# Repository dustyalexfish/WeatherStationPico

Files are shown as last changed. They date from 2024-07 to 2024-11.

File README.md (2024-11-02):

# WeatherStationPico
A data-logging weather station that uses a LCD display for user output, a potentiometer for user input, a DS3231 real time clock module and the DFRobot Weather Station v3.

The weather station is currently very buggy, and do not expect top-quality code, as I have not had years of experience with writing code for the Raspberry Pi Pico.

# Modifying the Code

In order to use the code, you will need to create a Pico Project, named WeatherStationPico. I recommend using a tool like the Raspberry Pi Pico Project Generator:  https://github.com/raspberrypi/pico-project-generator. You will need to download the Pico SDK and Pico Extras as well.

Compile the project for the first time, without the code, and then add in all of the code, and replace your CMakeLists.txt with the one specified in the project, replacing /path/to with your path to your Pico SDK and Pico Extras path.

# Required Parts

A Computer to Program the RPI Pico 

A 3D Printer (or an order from a 3D Printing company)

A roll of Filament (For your 3D printer)

**1** Raspberry Pi Pico               https://thepihut.com/products/raspberry-pi-pico?variant=41925332566211

**1** Half size Breadboard            https://thepihut.com/products/raspberry-pi-breadboard-half-size

**1** DFRobot Weather Station         https://thepihut.com/products/weather-station-kit-with-anemometer-wind-vane-rain-bucket

**1** Rotary Encoder                  (link needed)

**1** I2C LCD 16x2                    https://thepihut.com/products/i2c-16x2-arduino-lcd-display-module

**1** DS3231 RTC Module               https://tinyurl.com/ds3231-amazon

**~20** Male-to-Male Jumper Wires     https://thepihut.com/products/premium-male-male-jumper-wires-20-x-6-150mm
**~20** Male-to-Female Jumper Wires   https://thepihut.com/products/premium-female-male-extension-jumper-wires-20-x-12

**~20** M2.5 Screws and Nuts          https://thepihut.com/products/adafruit-black-nylon-screw-and-stand-off-set-m2-5-thread

A way to power the Raspberry Pi Pico (5V power required). I am using a Solar Panel to power my Weather Station.

# 3D Printing

In order to use this project, you will have to print the project box. The STL files and FreeCAD files are provided in the 3dmodels file for you to 3D print. I recommend printing out of ABS or PETG as PLA may warp in sunlight, unless you plan to keep the project box in the shade (which is possible, as the cables are quite long).

# Wiring

**LCD** Wire the LCD VCC-5V pin to your Raspberry Pi Pico 5V VBUS pin. Wire the GND pin to one of your Raspberry Pi Pico GND pins. Wire the SDA pin of your I2C lcd to GPIO6 on the Raspberry Pi Pico. Wire SCL on your LCD to GPIO7 on your Raspberry Pi Pico. 

**Rotary Encoder** Wire the CLK pin of your Rotary Encoder to GPIO pin two. Wire the DT pin to GPIO3. Wire the SW pin to GPIO4. Attach the + to your VBUS pin and the GND pin to one of the Raspberry Pi Pico's Ground pins.

**Weather Station** Wire the Weather Station Board TX pin to the Raspberry Pi Pico GPIO1. Wire the Weather Station Board RX pin to Raspberry Pi Pico GPIO0. Attach the 5V pin to VBUS, and the GND pin to one of the Raspberry Pi Pico's GND pins.

**DS3231 Module** Wire the I2C SDA pn to GPIO6 and the SCL pin to GPIO7. Attach the + pin to 5V and the GND pin to one of the Raspberry Pi Pico GND pins.

# Assembly

Once you have 3D printed the top lid of the case, you can screw in the LCD display with M2.5 screws to fix it in place. You will have to superglue the Rotary Encoder in place to the model. 

Wire all of the wires that exit the Weather Station board to exit through the holes in the top half of the project box. 

Once you have done this, plug in the Raspberry Pi Pico in to your PC, and upload the UF2 file provided (builds/WeatherStation-1.1) to your Raspberry Pi Pico. Screw in the lid, and you are now recording your own weather!

# Operation

In order to erase all data stored on Flash, hold down the potentiometer until the text 'Erase' appears on the display. Leave it to erase, and then reapply power to the device. In order to view previous logs, hold the potentiometer until two dots appear on the screen, and then scroll through logs that are stored on the system using the rotary encoder. For debug, hold down the rotary encoder until about 6 dots appear, and let go. You must be using a serial monitor to access the contents via USB, like Minicom. The system will dump data in flash in blocks of 256 to serial to access.

You now have a working Weather Station!

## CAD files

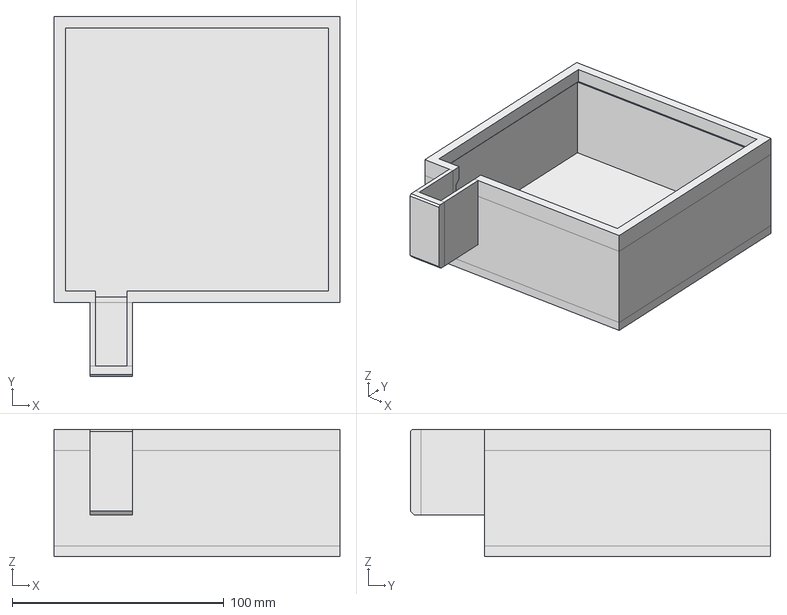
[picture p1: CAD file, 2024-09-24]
models/WeatherStationCap.FCStd
135.0 x 170.0 x 60.0 mm

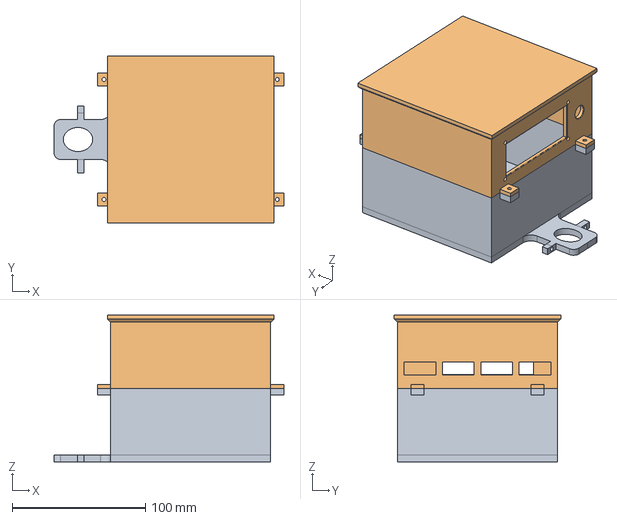
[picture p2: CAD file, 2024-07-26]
models/Project Box.FCStd
172.5 x 125.0 x 110.0 mm

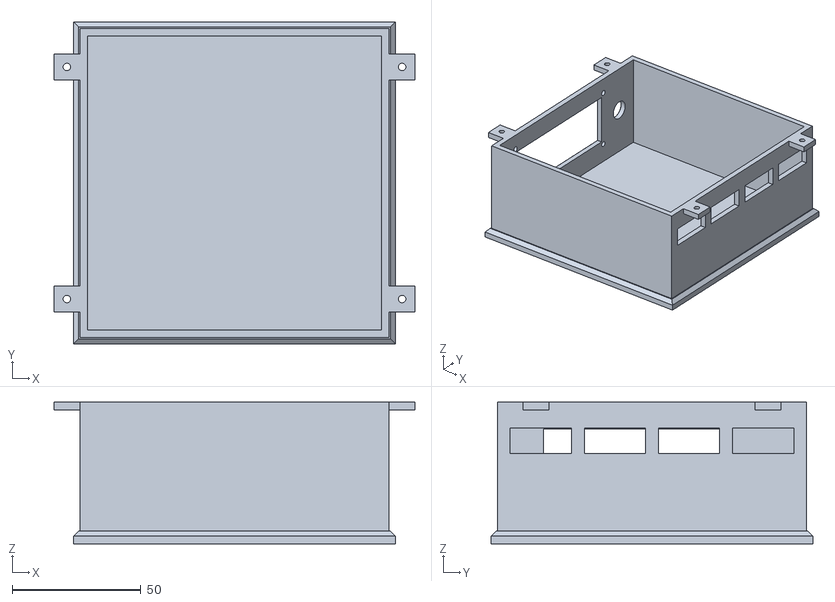
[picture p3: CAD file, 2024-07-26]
models/ProjectCase_top.stl
140.0 x 125.0 x 55.0

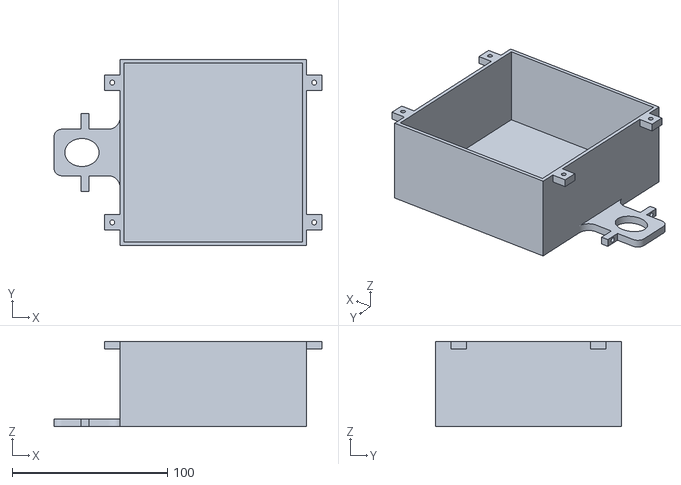
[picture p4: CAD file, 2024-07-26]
models/ProjectCase_bottom.stl
172.5 x 120.0 x 55.0

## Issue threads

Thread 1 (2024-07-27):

Pressure is flicking between being either too high or too low, only sometimes showing the correct air pressure

dustyalexfish, 2024-07-27:
The pressure reading on the Weather Station is sometimes wildly off the real pressure, either being around 3000 or 300hPa, only sometimes showing the actual air pressure

Closed 2024-07-27.

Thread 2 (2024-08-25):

The DS3231 is not reporting the year correctly

dustyalexfish, 2024-08-25:
When accessing the YEAR register on the DS3231, it reports 0b11111111, not the correct year. For a temporary fix, it currently just reports 2024

Closed 2024-09-22.

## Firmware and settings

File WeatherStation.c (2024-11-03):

#include "pico/sleep.h"
#include <math.h>

#include "hardware/rtc.h"
#include "pico/multicore.h"

#include "hardware/uart.h"
#include "hardware/i2c.h"
#include "hardware/irq.h"
#include "Recorder.h"
#include "lcd.h"
#include "RotaryEncoder.h"
#include "hardware/rtc.h"
#include "hardware/clocks.h"
#include "hardware/rosc.h"
#include "hardware/structs/scb.h"

#define LED_PIN 25
#define UART_ID uart0
#define BAUD_RATE 9600
#define DATA_BITS 8
#define PARITY UART_PARITY_NONE

#define STOP_BITS 1
#define UART_TX_PIN 0
#define UART_RX_PIN 1
#define I2C_SDA 6
#define I2C_SDL 7
#define SQW_PIN 16
#define I2C_PORT i2c1

#define MENUS 9

#define ENABLE_DORMANT true                  // Turn this ON if you are battery or solar powering your WeatherStation. However, Dormant mode is untested and is part of Pico Extras, so is unstable.
#define ENABLE_PROTOTYPE_LED false           // The onboard LED draws around 2 mA, and this is off to save that power
#define TURN_LCD_OFF_AFTER_TIME_EXPIRE true // I am not sure if turning this on reduces power, so it is by default off

int timeUntilLcdOffStart = 0;

const char* DIRECTIONS[8] = {"N ","NE", "E ", "SE", "S ", "SW", "W ", "NW"};
int time_since_interrupt();

const int ADDR = 0x27;

const int NUMBER_POT_STATES = 9;

volatile uint scb_orig;
volatile uint clock0_orig;
volatile uint clock1_orig;

static const char default_format[] = "%a %b %d %Y";

int intLen(int val)
{
  if (val <= 0)
  {
    return 1;
  }
  if (val <= 10)
  {
    return 1;
  }
  return (int)((ceil(log10(val))) * sizeof(char));
}

int shortLen(short val)
{
  if (val <= 0)
  {
    return 0;
  }
  return (int)((ceil(log10(val))) * sizeof(char));
}
bool display_flash_storage()
{
  lcd_home();
  char str[intLen(posInFlash / 20971)];
  sprintf(str, "%d", posInFlash / 20971);
  lcd_write_chars("Flash %: ", 9);
  lcd_write_chars(str, intLen(posInFlash / 16875));
  lcd_write_chars("%", 1);
  return true;
}

bool display_temp()
{
  lcd_home();
  int temperature = (((int)getTemperatureFromCompression()) - 32) * 5 / 9;
  char str[intLen(temperature)];
  sprintf(str, "%d", temperature);
  lcd_write_chars("Temperature: ", 13);
  lcd_write_chars(str, intLen(temperature));
  lcd_write_char('C');
  return true;
}
bool display_humid()
{
  lcd_home();
  int humidity = getHumidityFromCompression();
  char str[intLen(humidity) * sizeof(char)];
  sprintf(str, "%d", humidity);
  lcd_write_chars("Humidity: ", 10);
  lcd_write_chars(str, intLen(humidity) * sizeof(char));
  lcd_write_char('%');
  return true;
}

bool display_windSpeedAvg()
{
  lcd_home();
  int avgSpeed = getAvgSpeedFromCompression();
  char str[intLen(avgSpeed)];
  sprintf(str, "%d", avgSpeed);
  lcd_write_chars("Avg Spd: ", 9);
  lcd_write_chars(str, intLen(avgSpeed));
  lcd_write_chars("mph", 3);
  return true;
}
bool display_windSpeedFastest()
{
  lcd_home();
  int windSpeed = getFastestSpeedFromCompression();
  char str[intLen(windSpeed)];
  sprintf(str, "%d", windSpeed);
  lcd_write_chars("Fastest Speed: ", 15);
  lcd_home();
  shiftCursor(40);
  lcd_write_chars(str, intLen(windSpeed) * sizeof(char));
  lcd_write_chars("mph", 3);
  return false;
}
bool display_windRotation()
{
  lcd_home();
  int windRotation = getRotationFromCompression();
  lcd_write_chars("Wind Rot: ", 10);
  lcd_write_char(DIRECTIONS[windRotation][0]);
  lcd_write_char(DIRECTIONS[windRotation][1]);

  return true;
}
bool display_airPressure()
{
  lcd_home();
  int airPressure = getAirPressureFromCompression() / 10;
  char str[intLen(airPressure) * sizeof(char)];
  sprintf(str, "%d", airPressure);
  lcd_write_chars("Pressure: ", 10);
  lcd_write_chars(str, intLen(airPressure) * sizeof(char));

  return true;
}
bool display_rainfall_hour()
{
  lcd_home();
  int rainfall = (getRainfallOneHourFromCompression() * 25)/100;
  char str[intLen(rainfall)];
  sprintf(str, "%d", rainfall);
  lcd_write_chars("1h Rain: ", 9);
  lcd_write_chars(str, intLen(rainfall));
  lcd_write_chars("mm", 2);
  return true;
}
bool display_rainfall_day()
{
  lcd_home();
  int rainfall = (getRainfallOneDayFromCompression() * 25)/100;
  char str[intLen(rainfall)];
  sprintf(str, "%d", rainfall);
  lcd_write_chars("24h Rain: ", 10);
  lcd_write_chars(str, intLen(rainfall));
  lcd_write_chars("mm", 2);
  return true;
}

int pot_state = 0;
int tick_counter = 0;
int lastPotState = 0;

void initPins()
{
  stdio_uart_init();
  // stdio_usb_init();

  i2c_init(I2C_PORT, 50 * 1000);
  uart_init(UART_ID, BAUD_RATE);

  // LED

  uart_set_hw_flow(UART_ID, false, false);
  uart_set_format(UART_ID, DATA_BITS, STOP_BITS, PARITY);
  uart_set_fifo_enabled(UART_ID, false);
}

void updateLCD(int pot_state)
{
  if (lastPotState != pot_state)
  {
    lastPotState = pot_state;
    lcd_clear_screen();
  }
  lcd_home();
  // lcd_write_chars("Yay! ", 5);
  // busy_wait_ms(2);
  bool displayTime = true;

  switch (pot_state)
  {
  case 0:
    displayTime = display_flash_storage();
    break;
  case 2:
    displayTime = display_humid();
    break;
  case 3:
    displayTime = display_windSpeedAvg();
    break;
  case 4:
    displayTime = display_windSpeedFastest();
    break;
  case 5:
    displayTime = display_windRotation();
    break;
  case 6:
    displayTime = display_airPressure();
    break;
  case 7:
    displayTime = display_rainfall_hour();
    break;
  case 8:
    displayTime = display_rainfall_day();
    break;
  default:
    displayTime = display_temp();
    break;
  }

  if (displayTime)
  {
    lcd_home();
    char timeChars[intLen(wstime)];
    shiftCursor(40);
    sprintf(timeChars, "%d", wstime);
    lcd_write_chars("Time: ", 6);
    lcd_write_chars(timeChars, intLen(wstime));
  }
  // restore_interrupts(ints);
}

const int TIME_TURN_OFF = 10; // Turn off at 8:00 PM
const int TIME_TURN_ON = 7;   // turn back on at 7:00 AM

int scroll(int rotPos, int scrollBy, int numberOfFlashLogs)
{
  int rotPosition = rotPos;
  while (getRotaryEncoderSWPushState())
  {
    tight_loop_contents();
  }
  while (!getRotaryEncoderSWPushState())
  {
    getFlashLogContents(rotPosition);
    time_t rawtime = getTimeFromCompresion();
    struct tm ts;
    char buf[16];
    char buf2[16];
    for (int i = 0; i < 16; ++i)
    {
      buf[i] = ' ';
      buf2[i] = ' ';
    }
    // Format time, "ddd yyyy-mm-dd hh:mm:ss zzz"
    ts = *localtime(&rawtime);
    strftime(buf, sizeof(buf), "%a %d/%m/%Y", &ts);
    strftime(buf2, sizeof(buf2), "%H:%M:%S %Z", &ts);
    lcd_clear_screen();
    lcd_home();
    lcd_write_chars(buf, 16);
    shiftCursor(24);
    lcd_write_chars(buf2, 16);

    while (true)
    {
      int update = update_rotaryEncoder();
      if (update == ENCODER_CW)
      {
        rotPosition += scrollBy;
        rotPosition = rotPosition % numberOfFlashLogs;
        break;
      }
      if (update == ENCODER_CCW)
      {
        rotPosition -= scrollBy;
        if (rotPosition <= -1)
        {
          rotPosition = numberOfFlashLogs - 1;
        }
        rotPosition = rotPosition % numberOfFlashLogs;
        break;
      }
      if (getRotaryEncoderSWPushState())
      {
        break;
      }
    }
  }
  return rotPosition;
}
int numberRange(int max,char* question, int len, int start) {
  lcd_clear_screen();
  lcd_home();
  lcd_write_chars(question, len);

  while (getRotaryEncoderSWPushState())
  {
    tight_loop_contents();
  };
  int num = start;

  char str2[intLen(num)];
  sprintf(str2, "%d", num);
  shiftCursor(40-len);
  lcd_write_chars(str2, intLen(num));
  while(!getRotaryEncoderSWPushState()) {
    int update = update_rotaryEncoder();

    num = num % max;
    if (update == ENCODER_CW) {
      num++;
    } else if (update == ENCODER_CCW) {
      num--;
    }
    if(update != ENCODER_NO_ACTIVITY) {
      char str[intLen(num)];
      sprintf(str, "%d", num);
      lcd_home();
      shiftCursor(40);
      lcd_write_chars(str, intLen(num));
      lcd_write_chars("    ", 4); // Write a few spaces in order to not have a problem of 0 stuck on screen when going from 10 to 1
    }
  }
  while(getRotaryEncoderSWPushState()) {
    tight_loop_contents();
  }
  return num;
}
bool showLCDQuestion(char* question, int len) {

  lcd_clear_screen();
  lcd_home();
  lcd_write_chars(question, len);

  while (getRotaryEncoderSWPushState())
  {
    tight_loop_contents();
  };
  lcd_home();
  shiftCursor(41);
  lcd_write_chars("Y            N", 14);
  lcd_home();
  shiftCursor(53);
  lcd_write_char('>');
  bool answer = false;
  while (!getRotaryEncoderSWPushState())
  {
    sleep_us(1000);
    int update = update_rotaryEncoder();
    if (update == ENCODER_CW || update == ENCODER_CCW)
    {
      if (answer)
      {

        lcd_home();
        shiftCursor(53);
        lcd_write_char('>');
        answer = false;
        lcd_home();
        shiftCursor(40);
        lcd_write_char(' ');
      }
      else
      {
        lcd_home();
        shiftCursor(53);
        lcd_write_char(' ');
        answer = true;
        lcd_home();
        shiftCursor(40);
        lcd_write_char('>');
      }
    }
  }

  while(getRotaryEncoderSWPushState()) {
    tight_loop_contents();
  }
  return answer;
}
void showSetupWizard() {
  lcd_clear_screen();
  lcd_home();
  char WeatherStationPico[14] = "WeatherStation";
  for (int i = 0; i < 14; ++i)
  {
    lcd_write_char(WeatherStationPico[i]);
    sleep_ms(250);
  }
  shiftCursor(26);
  lcd_write_chars("V1.3.1dev", 9);

  while (!getRotaryEncoderSWPushState())
  {
    tight_loop_contents();
  };

  if (showLCDQuestion("Set Dir Offset?", 15))
  {
    bool takingData = false;
    int index = 0;

    lcd_clear_screen();
    lcd_write_chars("Correct Rotation", 16);
    shiftCursor(40-16);
    lcd_write_chars("Direction: ",11);
    
 
      
    while(!getRotaryEncoderSWPushState()) {

      char ch = uart_getc(UART_ID);

      if (ch == 'c')
      {

        takingData = true;
        index = 0;
      }

      if (takingData)
      {

        printf("%c", ch);
        buffer[index] = ch;
        index++;
        if (index == 35)
        {
          recordDataOntoArray();
          lcd_home();
          shiftCursor(51);
          lcd_write_char(getRotationFromCompression()+48);
          index = 0;
          takingData = false;
        }
      }
    }
    while(getRotaryEncoderSWPushState()) {
      tight_loop_contents();
    }
    
  }
  if(showLCDQuestion("Reset Flash?",12)) {
    if(showLCDQuestion("Are you sure?",13)) {
      lcd_clear_screen();
      lcd_home();
      lcd_write_chars("Erase", 5);
      printf("Erase\n");
      sleep_ms(3000);
      for (int i = 0; i < PICO_FLASH_SIZE_BYTES - RESERVED; i += 4096)
      {
        printf(".");

        lcd_home();
        shiftCursor(40);
        char str[intLen(i / 4096)];
        sprintf(str, "%d", i / 4096);
        lcd_write_chars(str, intLen(i / 4096));
        lcd_write_chars(" pages", 6);
        uint32_t interrupts = save_and_disable_interrupts();
        flash_range_erase(i + RESERVED, 4096);
        restore_interrupts(interrupts);
      }
      lcd_clear_screen();
      lcd_home();
      lcd_write_chars("Please restart", 14);
      printf("\nDone! Please restart now");
      while (true)
      {
        tight_loop_contents();
      };
    }
  }
  if(showLCDQuestion("Set time?", 9)) 
  {
    int year = numberRange(100, "Year", 4, getYear());
    int month = numberRange(12, "Month", 5, getMonth());
    int day = numberRange(31, "Day of Month", 12, getDayOfMonth());
    int hours = numberRange(24, "Hour (24)", 9, getHour());
    int minute = numberRange(60, "Minute", 6, getMinutes());
    int second = numberRange(60, "Second", 6, getSeconds());
    setTime(second, minute, hours, day, month, year);
  }
  while(getRotaryEncoderSWPushState()) {
    tight_loop_contents();
  }
  
}

void mainLoop()
{
  int index = 0;
  bool takingData = false;

  lcd_backlight_on();
  lcd_clear_screen();
  unsigned int record = 0;
  bool hasResultBeenTaken = false;
  timeUntilLcdOffStart = getUnixTime();
  char ch;
  while (true)
  {
    
    

    while(!uart_is_readable(UART_ID)) {
      int update = update_rotaryEncoder();
      if (update == ENCODER_CW) {
        
        pot_state += 1;
        pot_state = pot_state % NUMBER_POT_STATES;
      } else if (update == ENCODER_CCW) {
        if(pot_state == 0) {
          pot_state = NUMBER_POT_STATES-1;
        } else {
          pot_state -= 1;
        }
        
      }
      if(update != ENCODER_NO_ACTIVITY) {
        updateLCD(pot_state);
      }
    }
    ch = uart_getc(UART_ID);
    if (ch == 'c')
    {

      takingData = true;
      index = 0;
    }

    if (takingData)
    {

      printf("%c", ch);
      buffer[index] = ch;
      index++;
      if (index == 35)
      {
        hasResultBeenTaken = true;
        record++;
        wstime = getUnixTime();
        updateLCD(pot_state);
        index = 0;
        takingData = false;

        recordDataOntoArray();
        wstime = 0;
        if (getUnixTime() - timeUntilLcdOffStart > 30) // Only record if off to prevent uneven records
        {
          compressData(record < 10); // We dont compress at first to set values that are 0 to 0.
        }

      }
      if (getUnixTime() - timeUntilLcdOffStart > 30 && isBacklightOn())
      {
        lcd_backlight_off();
#if TURN_LCD_OFF_AFTER_TIME_EXPIRE
        lcd_turn_screen_off();
#endif
        sleep_ms(10);
      }
      else if (!isBacklightOn() && getUnixTime() - timeUntilLcdOffStart < 30)
      {
#if TURN_LCD_OFF_AFTER_TIME_EXPIRE
        lcd_turn_screen_on();
#endif
        lcd_backlight_on();
        sleep_ms(10);
      }
    }

    uint8_t potentiometerTime = 0;
    if (getRotaryEncoderSWPushState())
    {
      if (!isBacklightOn())
      {
        timeUntilLcdOffStart = getUnixTime();
        while (getRotaryEncoderSWPushState())
        {
          tight_loop_contents();
        }
      }
      lcd_clear_screen();
      sleep_ms(500);
      lcd_home();
    }
    while (getRotaryEncoderSWPushState())
    {
      potentiometerTime++;
      sleep_ms(1000);

      lcd_write_char('.');
      if (potentiometerTime >= 7)
      {

        showSetupWizard();
      }
    }
    if (potentiometerTime > 5)
    {
      lcd_clear_screen();
      lcd_home();
      sleep_ms(10);
      lcd_write_chars("Calc Climate", 12);
      sleep_ms(10);
      long temp = 0;
      long humidity = 0;
      long airPressure = 0;
      long windDir = 0;
      long avgWindSpeed = 0;
      long fastWindSpeed = 0;
      long rainfallOneHour = 0;
      long rainfall24Hour = 0;
      int position = 0;
      int numberOfFlashLogs = getNumberOfFlashLogs();
      while (position < numberOfFlashLogs)
      {
        if (readFlashLog(position + 4096) == TEMP_CHAR)
        {
          position++;
          dataRecorded[3] = readFlashLog(position + 4096);
        }
        else if (readFlashLog(position + 4096) == HUMIDITY_CHAR)
        {
          position++;
          dataRecorded[10] = readFlashLog(position + 4096);
        }
        else if (readFlashLog(position + 4096) == WIND_DIR_CHAR)
        {
          position++;
          dataRecorded[0] = readFlashLog(position + 4096);
        }
        else if (readFlashLog(position + 4096) == WIND_SPEED_CHAR)
        {
          position++;
          dataRecorded[1] = readFlashLog(position + 4096);
        }
        else if (readFlashLog(position + 4096) == WIND_TOP_SPEED_CHAR)
        {
          position++;
          dataRecorded[2] = readFlashLog(position + 4096);
        }
        else if (readFlashLog(position + 4096) == RAINFALL_ONE_HOUR_CHAR)
        {
          position += 2;
          dataRecorded[4] = readFlashLog(position + 4096 - 1);
          dataRecorded[5] = readFlashLog(position + 4096);
        }
        else if (readFlashLog(position + 4096) == RAINFALL_24_HOUR_CHAR)
        {
          position += 2;
          dataRecorded[6] = readFlashLog(position + 4096 - 1);
          dataRecorded[7] = readFlashLog(position + 4096);
        }
        else if (readFlashLog(position + 4096) == AIR_PRESSURE_CHAR)
        {
          position += 2;
          dataRecorded[8] = readFlashLog(position + 4096 - 1);
          dataRecorded[9] = readFlashLog(position + 4096);

        } else {
          position++;
        }

        temp += getTemperatureFromCompression();
        humidity += getHumidityFromCompression();
        airPressure += getAirPressureFromCompression();
        windDir += getAirPressureFromCompression();
        avgWindSpeed = getAvgSpeedFromCompression();
        fastWindSpeed = getFastestSpeedFromCompression();
        rainfallOneHour += getRainfallOneHourFromCompression();
        rainfall24Hour += getRainfallOneDayFromCompression();
        


      }

      temp = temp / numberOfFlashLogs;
      dataRecorded[3] = (char)temp;
      humidity = humidity / numberOfFlashLogs;
      dataRecorded[10] = (char)humidity;
      airPressure = airPressure / numberOfFlashLogs;
      dataRecorded[8] = (airPressure & 0b0000000011111111);
      dataRecorded[9] = (airPressure & 0b1111111100000000) >> 8;
      windDir = windDir / numberOfFlashLogs;
      dataRecorded[0] = windDir;
      avgWindSpeed = avgWindSpeed / numberOfFlashLogs;
      dataRecorded[1] = avgWindSpeed;
      fastWindSpeed = fastWindSpeed / numberOfFlashLogs;
      dataRecorded[2] = readFlashLog(position + 4096);
      rainfallOneHour = rainfallOneHour / numberOfFlashLogs;
      dataRecorded[4] = (rainfallOneHour & 0b0000000011111111);
      dataRecorded[5] = (rainfallOneHour & 0b1111111100000000) >> 8;
      rainfall24Hour = rainfall24Hour / numberOfFlashLogs;
      dataRecorded[6] = (rainfall24Hour & 0b0000000011111111);
      dataRecorded[7] = (rainfall24Hour & 0b1111111100000000) >> 8;

      updateLCD(pot_state);
      lcd_backlight_on();
      timeUntilLcdOffStart = getUnixTime();
      while (!getRotaryEncoderSWPushState()) {
        tight_loop_contents();
      }
    }

    else if (potentiometerTime > 1)
    {
      int numberOfFlashLogs = getNumberOfFlashLogs();
      int rotPosition = 0;
      bool exit = false;
      while (!exit)
      {
        rotPosition = scroll(rotPosition, 43200, numberOfFlashLogs);
        rotPosition = scroll(rotPosition, 1440, numberOfFlashLogs);
        rotPosition = scroll(rotPosition, 60, numberOfFlashLogs);
        rotPosition = scroll(rotPosition, 1, numberOfFlashLogs);
        if (getRotaryEncoderSWPushState())
        {
          lcd_clear_screen();
          lcd_home();
          updateLCD(pot_state);
          while (getRotaryEncoderSWPushState())
          {
          };
          sleep_ms(100);
          while (!getRotaryEncoderSWPushState())
          {
          };
          exit = true;
          break;
        }
      }
    }

#if ENABLE_DORMANT
    if (hasResultBeenTaken)
    {
      hasResultBeenTaken = false;

      #if ENABLE_PROTOTYPE_LED
        gpio_put(LED_PIN, 1);
      #endif

      scb_orig = scb_hw->scr;
      clock0_orig = clocks_hw->sleep_en0;
      clock1_orig = clocks_hw->sleep_en1;

      sleep_run_from_xosc();

      i2c_writeRTCdata(0xE, 0b00000001); // enable alarm
      for(int i = 0; i < 60; ++i) { // Sleep for 60 secs or until SW down
        if(getRotaryEncoderSWPushState() || getUnixTime() - timeUntilLcdOffStart <= 30) {
          break;
        }
        sleep_goto_dormant_until_pin(SQW_PIN, true, true);
        sleep_goto_dormant_until_pin(SQW_PIN, true, false);
      }


      // sleep_goto_dormant_until_pin(SQW_PIN, true, true);
      // while(!awake) {}

      // Re-enable ring Oscillator control
      rosc_write(&rosc_hw->ctrl, ROSC_CTRL_ENABLE_LSB);

      i2c_writeRTCdata(0xE, 0b00000000); // disable alarm

      // reset procs back to default
      scb_hw->scr = scb_orig;
      clocks_hw->sleep_en0 = clock0_orig;
      clocks_hw->sleep_en1 = clock1_orig;

      // stdio_usb_init();
      stdio_uart_init();

      i2c_init(I2C_PORT, 50 * 1000);
      uart_init(UART_ID, BAUD_RATE);

      gpio_put(LED_PIN, 0);
    }
#endif
  }
}

int main()
{
  gpio_set_function(UART_TX_PIN, GPIO_FUNC_UART);
  gpio_set_function(UART_RX_PIN, GPIO_FUNC_UART);
  gpio_init(SQW_PIN);
  gpio_init(LED_PIN);
  gpio_set_dir(LED_PIN, GPIO_OUT);
  gpio_set_dir(SQW_PIN, GPIO_IN);

  gpio_set_function(I2C_SDA, GPIO_FUNC_I2C);
  gpio_set_function(I2C_SCL, GPIO_FUNC_I2C);
  gpio_pull_up(I2C_SDA);
  gpio_pull_up(I2C_SCL);
  gpio_pull_up(SQW_PIN);

  initPins();
  init_lcd();


  // DS3231 SQW Alarm for Waiting
  i2c_writeRTCdata(0x7, 0b10000000);
  i2c_writeRTCdata(0x8, 0b10000000);
  i2c_writeRTCdata(0x9, 0b10000000);
  i2c_writeRTCdata(0xA, 0b10000000);
  i2c_writeRTCdata(0xE, 0b00000001);

  recorder_init();
  init_rotaryEncoder();
  if (!isFormatted())
  {
    showSetupWizard();
    lcd_clear_screen();
    lcd_home();
    lcd_write_chars("Erasing data", 12);
    if (isFormatted(0))
    {
      eraseBlock(0);
    }
    writePrimarySignature();
    sleep_ms(1000);
    lcd_clear_screen();
    lcd_home();
  }

  findPosInFlash();
  mainLoop();
}

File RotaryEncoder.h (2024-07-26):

//Non-PIO implementation of a rotary encoder system. 

#pragma once
#include <stdio.h>
#include "pico/stdlib.h"

#define ENCODER_CLK 2
#define ENCODER_DT  3
#define ENCODER_SW  4

#define ENCODER_NO_ACTIVITY 0
#define ENCODER_CCW 1
#define ENCODER_CW 2
#define ENCODER_SW_PUSHED 3
bool lastState;

void init_rotaryEncoder() {
    gpio_init(ENCODER_CLK);
    gpio_init(ENCODER_DT);
    gpio_init(ENCODER_SW);

    gpio_set_dir(ENCODER_CLK, GPIO_IN);
    gpio_set_dir(ENCODER_DT,  GPIO_IN);
    gpio_set_dir(ENCODER_SW,  GPIO_IN);

    gpio_pull_up(ENCODER_CLK);
    gpio_pull_up(ENCODER_SW);

    lastState = gpio_get(ENCODER_CLK);

    
}

int update_rotaryEncoder() {
    
    bool currentState = gpio_get(ENCODER_CLK);
    if(currentState != lastState && currentState == false) {
        lastState = currentState;
        if(gpio_get(ENCODER_DT)) {
            return ENCODER_CCW;
        } else {
            return ENCODER_CW;
        }
    }

    lastState = currentState;

    return ENCODER_NO_ACTIVITY;
}

bool getRotaryEncoderSWPushState() {
    return !gpio_get(ENCODER_SW);
}

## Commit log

2024-07-25 Library for interfacing a Rotary Encoder
2024-07-26 Added a command for getting Switch state
2024-07-26 Inverted CCW and CW
    [RotaryEncoder.h]
2024-07-26 Added m2.5 screws to needed parts
2024-07-26 Add project case STL files to project
    [ProjectCase_bottom.stl, ProjectCase_top.stl]
2024-07-26 Move ProjectCase to a seperate folder
    [ProjectCase_bottom.stl]
2024-07-26 Add Project Box CAD to the models folder
    [Project Box.FCStd]
2024-07-27 Added 'A way to power your RPi Pico'
2024-07-27 Add assembly instructions and required operating instructions
2024-07-27 Fix Double Rain 1H
    [WeatherStation.c]
2024-07-27 Fixed Pressure Not Recording
    [Recorder.h]
2024-07-27 Reduced logging to speed up device
2024-07-27 Fixed invalid readings for air pressure
    [WeatherStation.h]
2024-07-27 Fixed Air Pressure Reading
    [WeatherStation.h]
2024-07-28 Removed printf from getUnixTiem
2024-07-28 Data is only recorded every 1 minute now (temporary fix)
    [WeatherStation.c]
2024-08-25 Reduced on printing to USB
2024-08-25 Removed random printf statement
2024-08-25 Fixed an issue where a single digit number was displaying empty
    Fixed the issue where single digit recordings are displaying as ''. Eg, if the wind speed was 5, it was reporting 'Wind Speed: mph', not 'Wind Speed: 5mph'.
    [WeatherStation.c]
2024-08-26 Removed the LED delay and the LED flashing during recordings
2024-09-21 Added the ability to write data to the RTC on I2C
2024-09-22 Removed printfs as they are unavailable with USB
2024-09-22 Fixed Year Bug
    The Year Bug has finally been removed from the code!
    I am adding a Set RTC feature to RTC.h
    [RTC.h]
2024-09-22 Reversed USB changes as caused problems
    [WeatherStation.c]
2024-09-22 Added Calc Climate in replacement of Dump Output
    [WeatherStation.c]
2024-09-24 Add WeatherStationCap to models
    [WeatherStationCap.FCStd]
2024-09-24 Fixed Formula for display Rainfall
    [WeatherStation.c]
2024-09-24 Fixed Prototype LED problem
    [WeatherStation.c]
2024-09-24 Weather Station 1.3 update
    Fixes Year Bug, Dormant mode Added, Power Reduced, Screen Off.
2024-11-02 Switched Female-to-Female to Male-to-Male
2024-11-03 Added 'Setup' menu replacing Erase data option
    Added setup menu, setting time and helping you align the Weather Station wind vane correctly. It also has an option for erasing all flash (except program flash)
    [WeatherStation.c]
2024-11-03 Fixed an issue with first boot after erase
    [WeatherStation.c]
2024-11-03 Added a potentiometer scrolling system (unreliable currently)
